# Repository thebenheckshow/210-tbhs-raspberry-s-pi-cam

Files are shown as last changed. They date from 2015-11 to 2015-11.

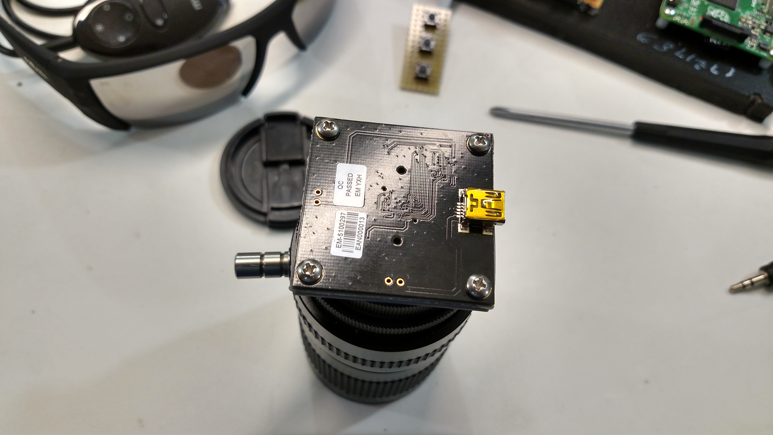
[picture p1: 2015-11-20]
Pictures/IMG_20151013_200145252_HDR.jpg

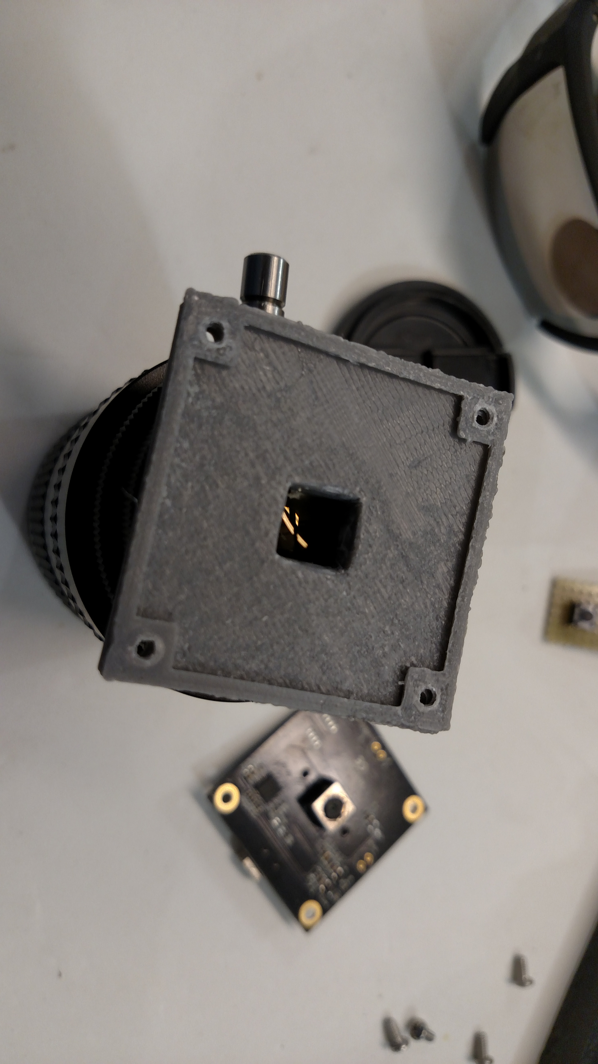
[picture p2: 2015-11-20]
Pictures/IMG_20151013_195946254.jpg

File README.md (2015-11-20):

# 210-tbhs-raspberry-s-pi-cam

The evil Pie Face plans to turn the world to crust, special agent Ben Bondendorf must stop him. In order for Ben to accomplish this he must build some sort of surveillance device that will enable him to stop Pie Face before his evil plan is realized. 

In the first episode Ben and Felix complete the mechanical portion of the build.
http://www.element14.com/community/docs/DOC-79156/l/episode-210-ben-hecks-raspberry-s-pi-cam-part-1-episode

In the second episode Ben and Felix create a control box in the handle of the cooler, write an auto start script for the Pi2, and wire everything together.
http://www.element14.com/community/docs/DOC-79191/l/episode-211-ben-hecks-raspberry-s-pi-cam-part-2-episode

Join the element14 community! - http://www.element14.com/tbhs

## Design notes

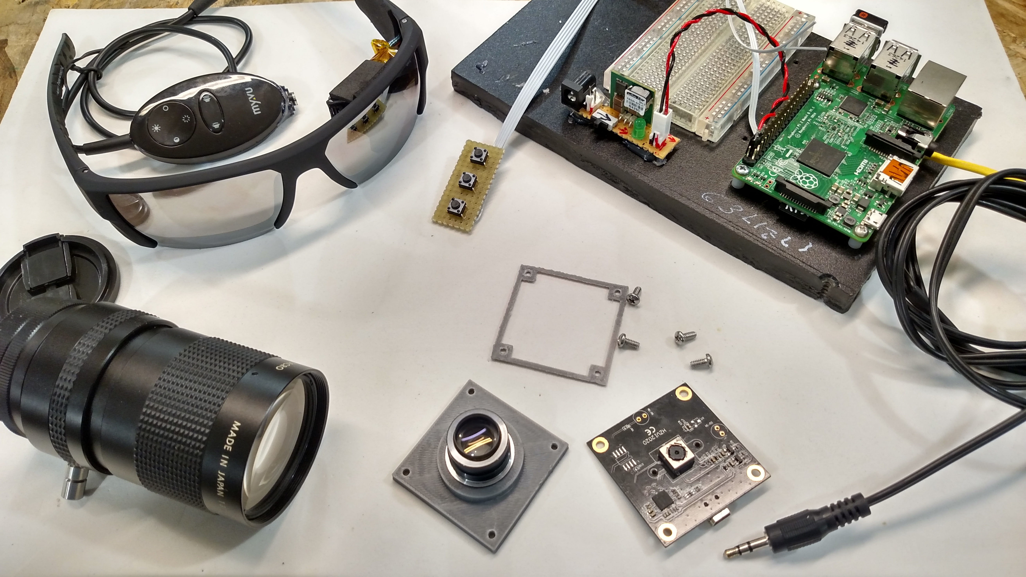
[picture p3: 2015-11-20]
Pictures/IMG_20151013_195322977_HDR.jpg

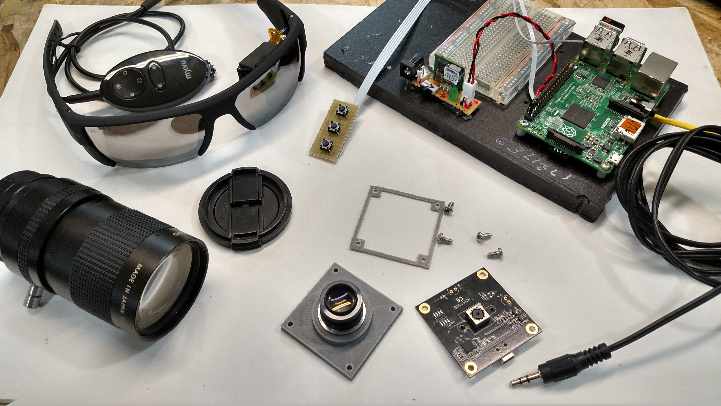
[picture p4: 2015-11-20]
Pictures/IMG_20151013_195359626_HDR.jpg

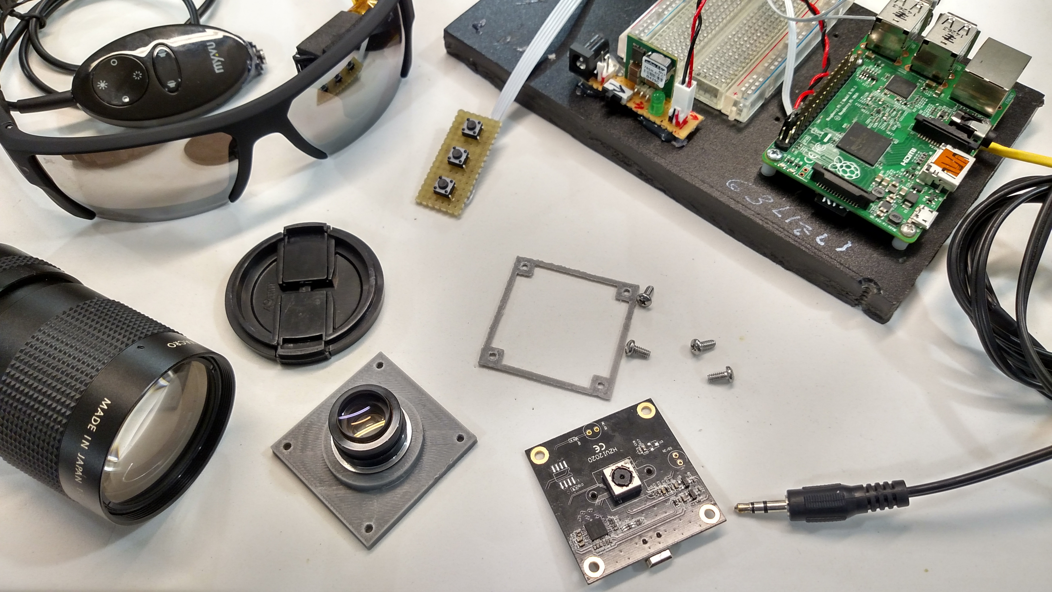
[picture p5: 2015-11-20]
Pictures/IMG_20151013_195439271_HDR.jpg

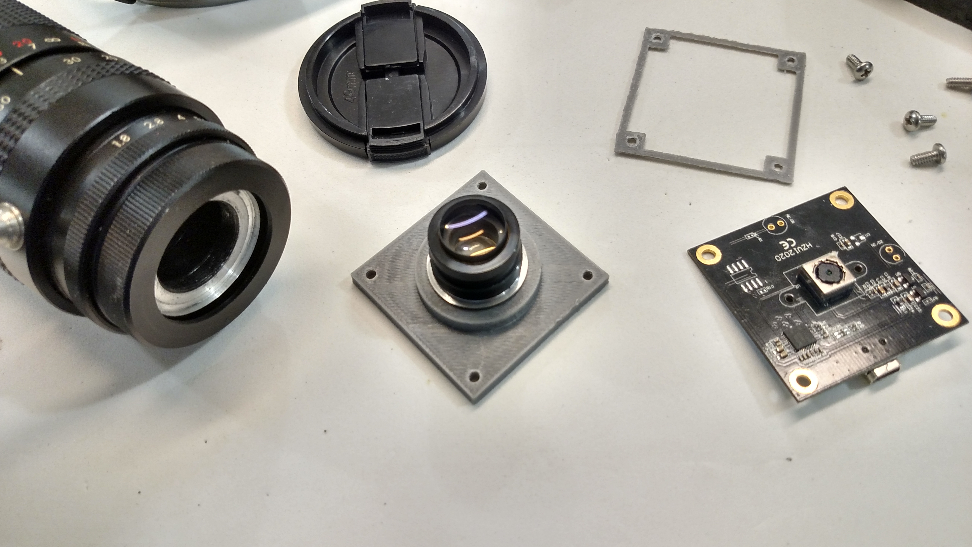
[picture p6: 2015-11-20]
Pictures/IMG_20151013_195614979_HDR.jpg

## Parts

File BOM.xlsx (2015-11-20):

Part | SKU | QTY | Supplier
Raspberry Pi 2 | 38Y6467 | 1 | Newark
PCB Board with isolated solder pads | 01H8753 | 1 | Newark
SWITCH, TACTILE SPST | 19C7994 | 4 | Newark
Through Hole Resistor, Carbon Film, MCF Series, 1 kohm | 38K0327 | 4 | Newark
CAM8200-U MODULE CAMERA MODULE, USB INTERFACE, 5MP | 83X8624 | 1 | Newark
BOARD-BOARD CONNECTOR, SOCKET, 36 POSITION, 1ROW | 18M8296 | 1 | Newark
Linear Regulator DC/DC Converter | 40M6586 | 1 | Newark
Audio cable | 90C0959 | 1 | Newark
Tactile Switch | 19C8258 | 3 | Newark
Kowa TV Zoom Lense 1:1.8/12.5-75 Macro | 1301700 | 1 | Ebay
Wireless dongle | 2638 | 1 | Adafruit
Myvu Personal Media Viewer |  | 1 | Amazon

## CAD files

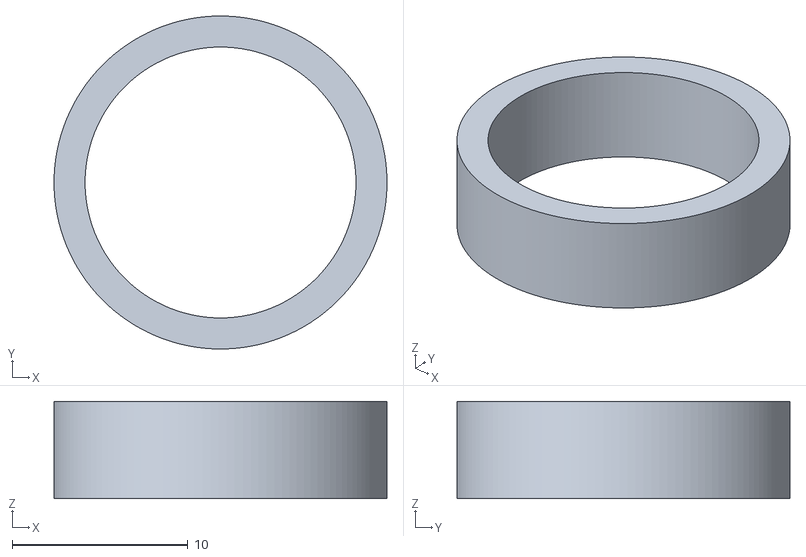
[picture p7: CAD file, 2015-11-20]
Design/Camera_Mount/Outer_Ring_Test.stl
18.9 x 18.9 x 5.54

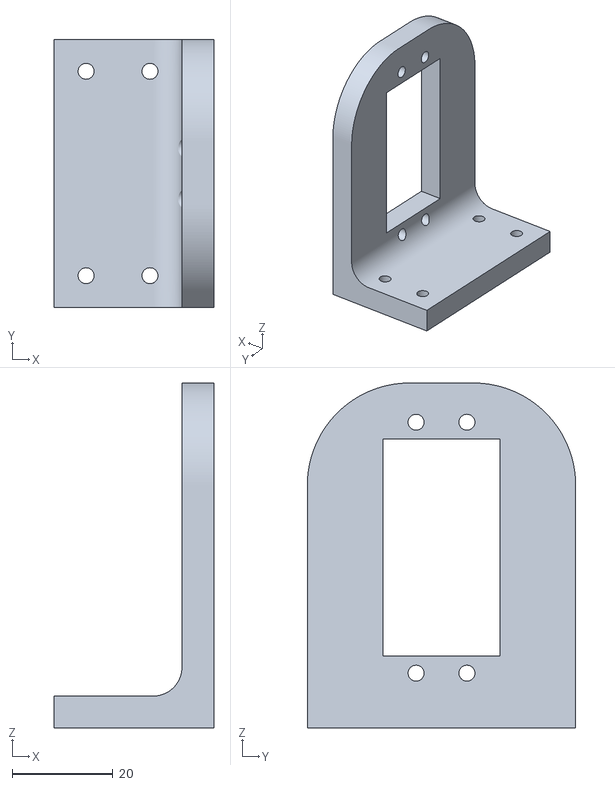
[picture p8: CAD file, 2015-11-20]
Design/STL/Servo Mount.stl
31.8 x 53.3 x 68.6

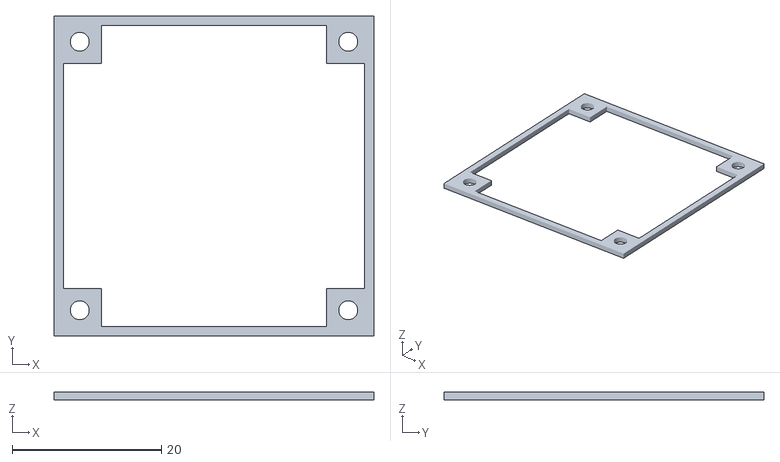
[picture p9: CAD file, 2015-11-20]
Design/STL/spacer.stl
43.0 x 43.0 x 1.02

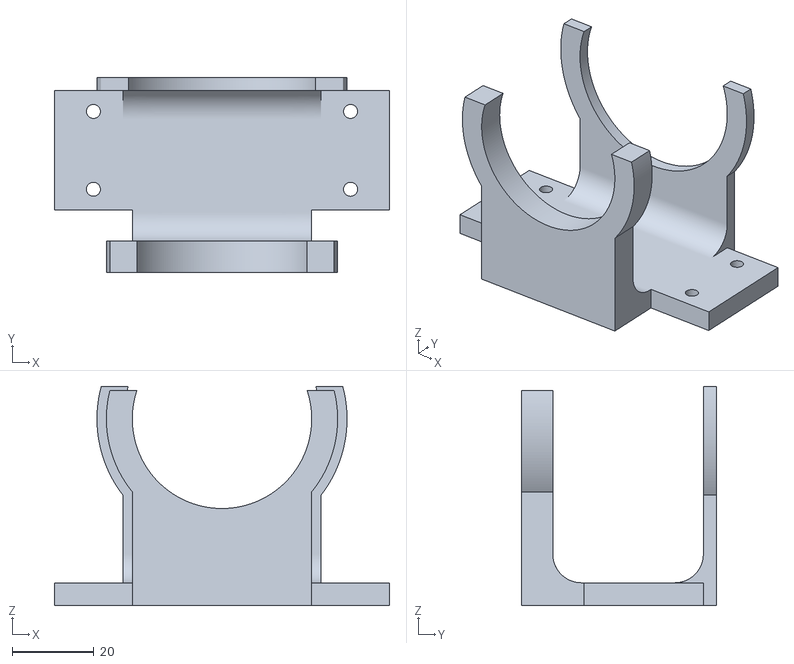
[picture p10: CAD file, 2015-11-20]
Design/STL/rings.stl
82.0 x 47.6 x 53.6

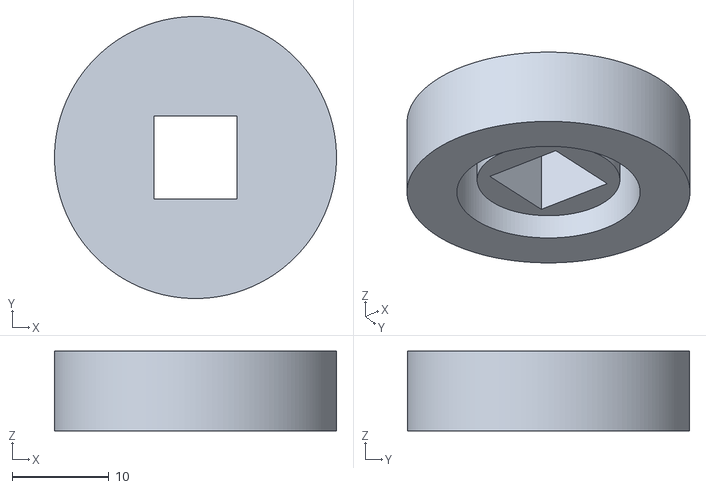
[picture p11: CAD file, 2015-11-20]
Design/STL/camera_mount_test_0.stl
29.2 x 29.2 x 8.26

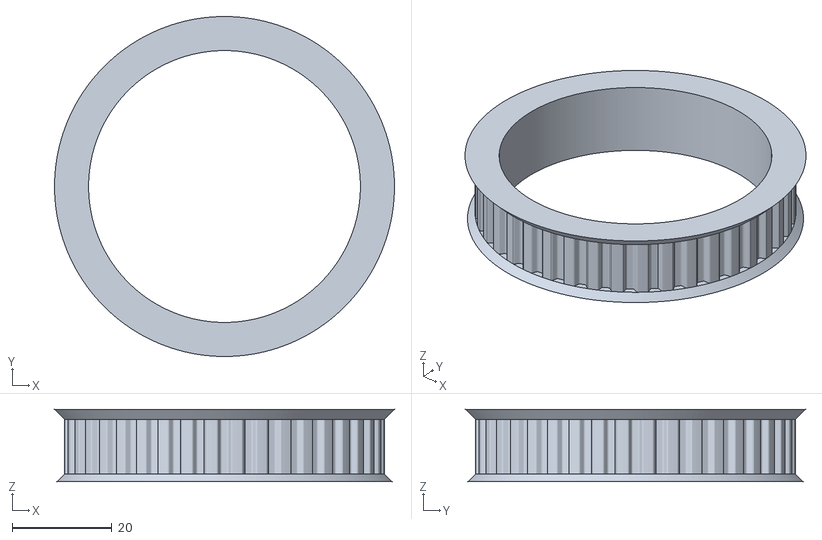
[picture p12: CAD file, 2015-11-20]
Design/STL/zoom pulley.stl
68.2 x 68.2 x 14.5

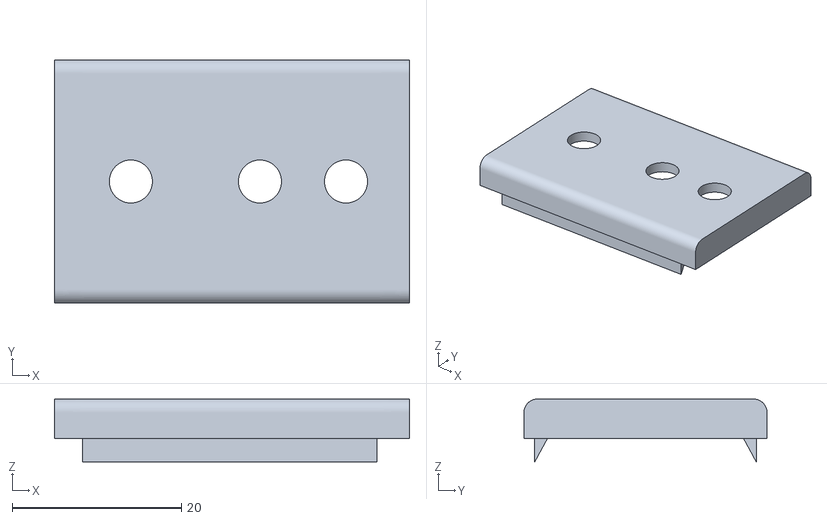
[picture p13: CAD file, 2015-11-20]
Design/STL/top cap.stl
41.9 x 28.7 x 7.43

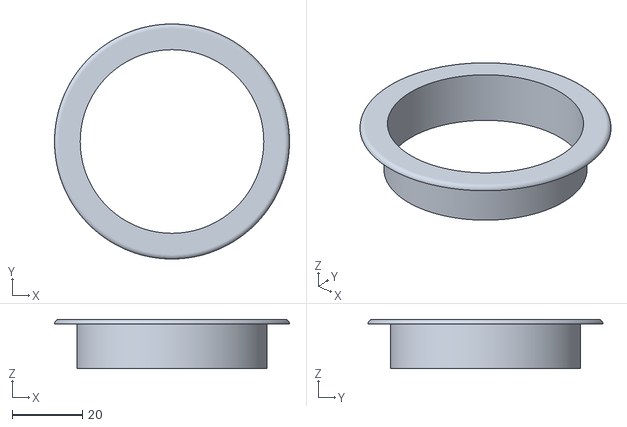
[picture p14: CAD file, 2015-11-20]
Design/STL/Adapter Ring.stl
66.7 x 66.7 x 14.0

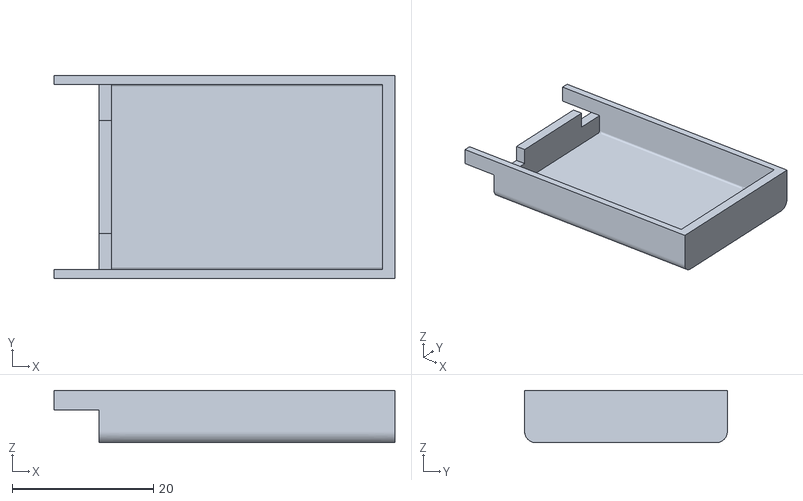
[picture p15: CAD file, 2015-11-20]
Design/STL/bottom cap.stl
48.3 x 28.7 x 7.43

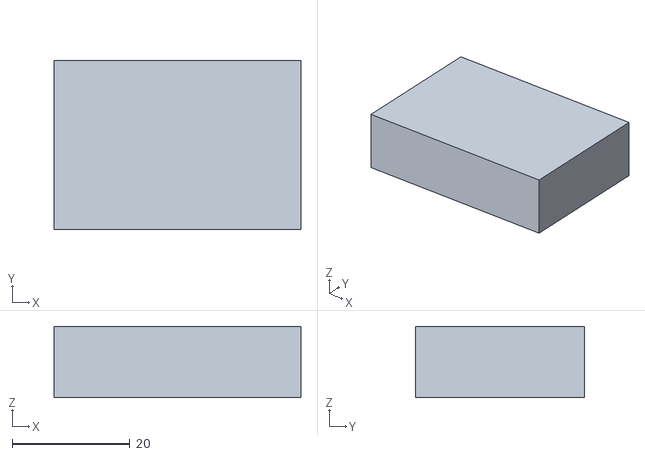
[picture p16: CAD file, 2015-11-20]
Design/STL/handle test 1.stl
41.9 x 28.7 x 12.1

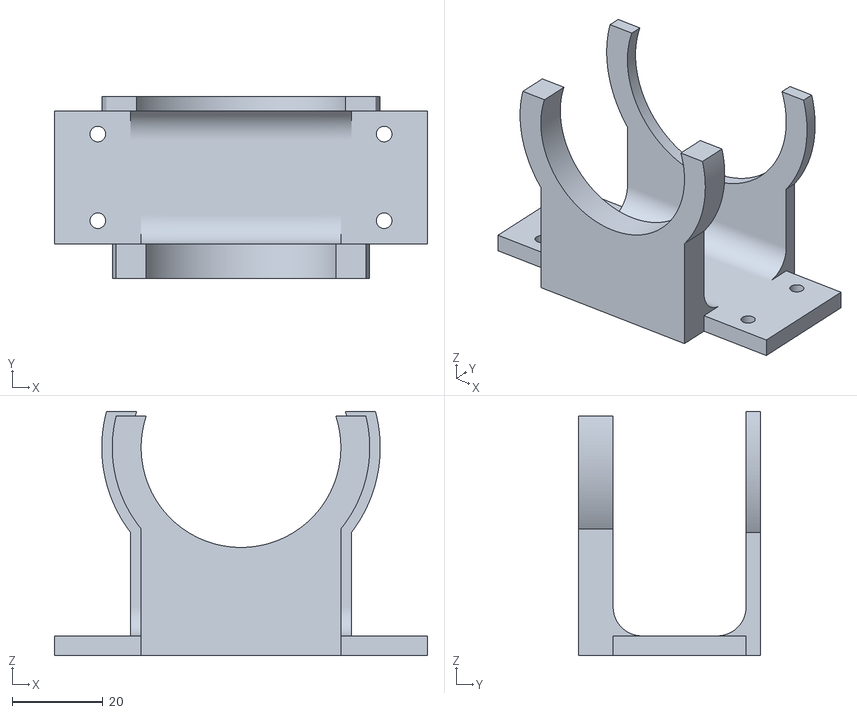
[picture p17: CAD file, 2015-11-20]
Design/STL/ring 2.stl
82.0 x 40.0 x 53.6

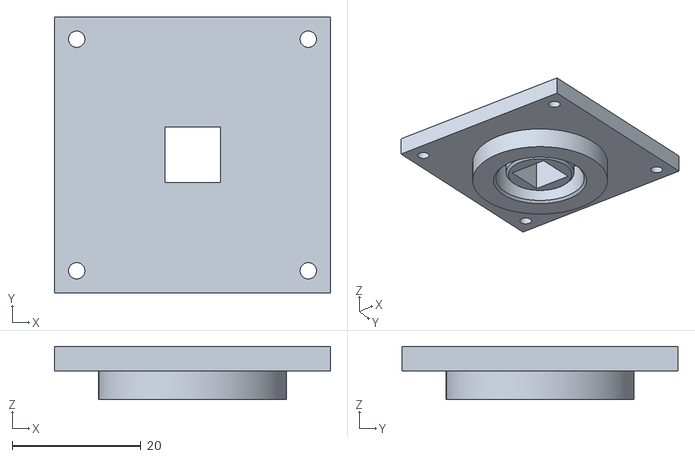
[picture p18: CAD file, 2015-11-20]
Design/STL/camera_mount_test_2.stl
43.0 x 43.0 x 8.26

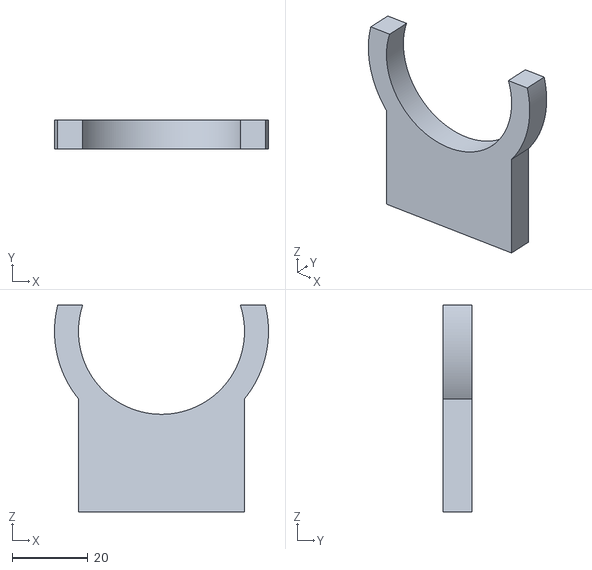
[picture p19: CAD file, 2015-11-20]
Design/STL/ring 1.stl
56.6 x 7.62 x 54.6

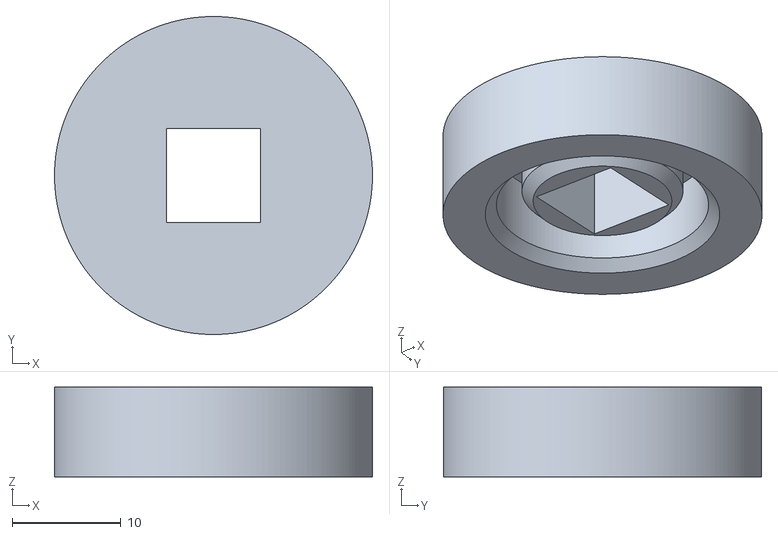
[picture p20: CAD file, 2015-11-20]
Design/STL/camera_mount_test_1.stl
29.2 x 29.2 x 8.26

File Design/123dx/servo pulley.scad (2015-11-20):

// Parametric Pulley with multiple belt profiles
// by droftarts January 2012

// Based on pulleys by:
// http://www.thingiverse.com/thing:11256 by me!
// https://github.com/prusajr/PrusaMendel by Josef Prusa
// http://www.thingiverse.com/thing:3104 by GilesBathgate
// http://www.thingiverse.com/thing:2079 by nophead

// dxf tooth data from http://oem.cadregister.com/asp/PPOW_Entry.asp?company=915217&elementID=07807803/METRIC/URETH/WV0025/F
// pulley diameter checked and modelled from data at http://www.sdp-si.com/D265/HTML/D265T016.html

/**
 * @name Pulley
 * @category Printed
 * @using 1 x m3 nut, normal or nyloc
 * @using 1 x m3x10 set screw or 1 x m3x8 grub screw
 */


// tuneable constants

teeth = 30;			// Number of teeth, standard Mendel T5 belt = 8, gives Outside Diameter of 11.88mm
profile = 3;		// 1=MXL 2=40DP 3=XL 4=H 5=T2.5 6=T5 7=T10 8=AT5 9=HTD_3mm 10=HTD_5mm 11=HTD_8mm 12=GT2_2mm 13=GT2_3mm 14=GT2_5mm

motor_shaft = 7.2;	// NEMA17 motor shaft exact diameter = 5
m3_dia = 3.5;		// 3mm hole diameter
m3_nut_hex = 1;		// 1 for hex, 0 for square nut
m3_nut_flats = 5.9;	// normal M3 hex nut exact width = 5.5
m3_nut_depth = 2.9;	// normal M3 hex nut exact depth = 2.4, nyloc = 4

retainer = 1;		// Belt retainer above teeth, 0 = No, 1 = Yes
retainer_ht = 2;	// height of retainer flange over pulley, standard = 1.5
idler = 1;			// Belt retainer below teeth, 0 = No, 1 = Yes
idler_ht = 1.5;		// height of idler flange over pulley, standard = 1.5

pulley_t_ht = 11;	// length of toothed part of pulley, standard = 12
pulley_b_ht = 0;		// pulley base height, standard = 8. Set to same as idler_ht if you want an idler but no pulley.
pulley_b_dia = 42;	// pulley base diameter, standard = 20
no_of_nuts = 2;		// number of captive nuts required, standard = 1
nut_angle = 180;		// angle between nuts, standard = 90
nut_shaft_distance = 5;	// distance between inner face of nut and shaft, can be negative.


//	********************************
//	** Scaling tooth for good fit **
//	********************************
/*	To improve fit of belt to pulley, set the following constant. Decrease or increase by 0.1mm at a time. We are modelling the *BELT* tooth here, not the tooth on the pulley. Increasing the number will *decrease* the pulley tooth size. Increasing the tooth width will also scale proportionately the tooth depth, to maintain the shape of the tooth, and increase how far into the pulley the tooth is indented. Can be negative */

additional_tooth_width = 0.2; //mm

//	If you need more tooth depth than this provides, adjust the following constant. However, this will cause the shape of the tooth to change.

additional_tooth_depth = 0; //mm

// calculated constants

nut_elevation = pulley_b_ht/2;
m3_nut_points = 2*((m3_nut_flats/2)/cos(30)); // This is needed for the nut trap

// The following set the pulley diameter for a given number of teeth

MXL_pulley_dia = tooth_spacing (2.032,0.254);
40DP_pulley_dia = tooth_spacing (2.07264,0.1778);
XL_pulley_dia = tooth_spacing (5.08,0.254);
H_pulley_dia = tooth_spacing (9.525,0.381);
T2_5_pulley_dia = tooth_spaceing_curvefit (0.7467,0.796,1.026);
T5_pulley_dia = tooth_spaceing_curvefit (0.6523,1.591,1.064);
T10_pulley_dia = tooth_spacing (10,0.93);
AT5_pulley_dia = tooth_spaceing_curvefit (0.6523,1.591,1.064);
HTD_3mm_pulley_dia = tooth_spacing (3,0.381);
HTD_5mm_pulley_dia = tooth_spacing (5,0.5715);
HTD_8mm_pulley_dia = tooth_spacing (8,0.6858);
GT2_2mm_pulley_dia = tooth_spacing (2,0.254);
GT2_3mm_pulley_dia = tooth_spacing (3,0.381);
GT2_5mm_pulley_dia = tooth_spacing (5,0.5715);

// The following calls the pulley creation part, and passes the pulley diameter and tooth width to that module

if ( profile == 1 ) { pulley ( "MXL" , MXL_pulley_dia , 0.508 , 1.321 ); }
if ( profile == 2 ) { pulley ( "40 D.P." , 40DP_pulley_dia , 0.457 , 1.226 ); }
if ( profile == 3 ) { pulley ( "XL" , XL_pulley_dia , 1.27, 3.051 ); }
if ( profile == 4 ) { pulley ( "H" , H_pulley_dia ,1.905 , 5.359 ); }
if ( profile == 5 ) { pulley ( "T2.5" , T2_5_pulley_dia , 0.7 , 1.678 ); }
if ( profile == 6 ) { pulley ( "T5" , T5_pulley_dia , 1.19 , 3.264 ); }
if ( profile == 7 ) { pulley ( "T10" , T10_pulley_dia , 2.5 , 6.13 ); }
if ( profile == 8 ) { pulley ( "AT5" , AT5_pulley_dia , 1.19 , 4.268 ); }
if ( profile == 9 ) { pulley ( "HTD 3mm" , HTD_3mm_pulley_dia , 1.289 , 2.27 ); }
if ( profile == 10 ) { pulley ( "HTD 5mm" , HTD_5mm_pulley_dia , 2.199 , 3.781 ); }
if ( profile == 11 ) { pulley ( "HTD 8mm" , HTD_8mm_pulley_dia , 3.607 , 6.603 ); }
if ( profile == 12 ) { pulley ( "GT2 2mm" , GT2_2mm_pulley_dia , 0.764 , 1.494 ); }
if ( profile == 13 ) { pulley ( "GT2 3mm" , GT2_3mm_pulley_dia , 1.169 , 2.31 ); }
if ( profile == 14 ) { pulley ( "GT2 5mm" , GT2_5mm_pulley_dia , 1.969 , 3.952 ); }

// Functions

function tooth_spaceing_curvefit (b,c,d)
	= ((c * pow(teeth,d)) / (b + pow(teeth,d))) * teeth ;

function tooth_spacing(tooth_pitch,pitch_line_offset)
	= (2*((teeth*tooth_pitch)/(3.14159265*2)-pitch_line_offset)) ;

// Main Module

module pulley( belt_type , pulley_OD , tooth_depth , tooth_width )
	{
	echo (str("Belt type = ",belt_type,"; Number of teeth = ",teeth,"; Pulley Outside Diameter = ",pulley_OD,"mm "));
	tooth_distance_from_centre = sqrt( pow(pulley_OD/2,2) - pow((tooth_width+additional_tooth_width)/2,2));
	tooth_width_scale = (tooth_width + additional_tooth_width ) / tooth_width;
	tooth_depth_scale = ((tooth_depth + additional_tooth_depth ) / tooth_depth) ;


//	************************************************************************
//	*** uncomment the following line if pulley is wider than puller base ***
//	************************************************************************

//	translate ([0,0, pulley_b_ht + pulley_t_ht + retainer_ht ]) rotate ([0,180,0])

	difference()
	 {	 
		union()
		{
			//base
	
			if ( pulley_b_ht < 2 ) { echo ("CAN'T DRAW PULLEY BASE, HEIGHT LESS THAN 2!!!"); } else {
				rotate_extrude($fn=pulley_b_dia*2)
				{
						square([pulley_b_dia/2-1,pulley_b_ht]);
						square([pulley_b_dia/2,pulley_b_ht-1]);
						translate([pulley_b_dia/2-1,pulley_b_ht-1]) circle(1);
				}
			}
	
		difference()
			{
			//shaft - diameter is outside diameter of pulley
			
			translate([0,0,pulley_b_ht]) 
			rotate ([0,0,360/(teeth*4)]) 
			cylinder(r=pulley_OD/2,h=pulley_t_ht, $fn=teeth*4);
	
			//teeth - cut out of shaft
		
			for(i=[1:teeth]) 
			rotate([0,0,i*(360/teeth)])
			translate([0,-tooth_distance_from_centre,pulley_b_ht -1]) 
			scale ([ tooth_width_scale , tooth_depth_scale , 1 ]) 
			{
			if ( profile == 1 ) { MXL();}
			if ( profile == 2 ) { 40DP();}
			if ( profile == 3 ) { XL();}
			if ( profile == 4 ) { H();}
			if ( profile == 5 ) { T2_5();}
			if ( profile == 6 ) { T5();}
			if ( profile == 7 ) { T10();}
			if ( profile == 8 ) { AT5();}
			if ( profile == 9 ) { HTD_3mm();}
			if ( profile == 10 ) { HTD_5mm();}
			if ( profile == 11 ) { HTD_8mm();}
			if ( profile == 12 ) { GT2_2mm();}
			if ( profile == 13 ) { GT2_3mm();}
			if ( profile == 14 ) { GT2_5mm();}
			}

			}
			
		//belt retainer / idler
		if ( retainer > 0 ) {translate ([0,0, pulley_b_ht + pulley_t_ht ]) 
		rotate_extrude($fn=teeth*4)  
		polygon([[0,0],[pulley_OD/2,0],[pulley_OD/2 + retainer_ht , retainer_ht],[0 , retainer_ht],[0,0]]);}
		
		if ( idler > 0 ) {translate ([0,0, pulley_b_ht - idler_ht ]) 
		rotate_extrude($fn=teeth*4)  
		polygon([[0,0],[pulley_OD/2 + idler_ht,0],[pulley_OD/2 , idler_ht],[0 , idler_ht],[0,0]]);}
	
		}
	   
		//hole for motor shaft
		translate([0,0,-1])cylinder(r=motor_shaft/2,h=pulley_b_ht + pulley_t_ht + retainer_ht + 2,$fn=motor_shaft*4);
				
		//captive nut and grub screw holes
	
		if ( pulley_b_ht < m3_nut_flats ) { echo ("CAN'T DRAW CAPTIVE NUTS, HEIGHT LESS THAN NUT DIAMETER!!!"); } else {
		if ( (pulley_b_dia - motor_shaft)/2 < m3_nut_depth + 3 ) { echo ("CAN'T DRAW CAPTIVE NUTS, DIAMETER TOO SMALL FOR NUT DEPTH!!!"); } else {
	
			for(j=[1:no_of_nuts]) rotate([0,0,j*nut_angle])
			translate([0,0,nut_elevation])rotate([90,0,0])
	
			union()
			{
				//entrance
				translate([0,-pulley_b_ht/4-0.5,motor_shaft/2+m3_nut_depth/2+nut_shaft_distance]) cube([m3_nut_flats,pulley_b_ht/2+1,m3_nut_depth],center=true);
	
				//nut
				if ( m3_nut_hex > 0 )
					{
						// hex nut
						translate([0,0.25,motor_shaft/2+m3_nut_depth/2+nut_shaft_distance]) rotate([0,0,30]) cylinder(r=m3_nut_points/2,h=m3_nut_depth,center=true,$fn=6);
					} else {
						// square nut
						translate([0,0.25,motor_shaft/2+m3_nut_depth/2+nut_shaft_distance]) cube([m3_nut_flats,m3_nut_flats,m3_nut_depth],center=true);
					}
	
				//grub screw hole
				rotate([0,0,22.5])cylinder(r=m3_dia/2,h=pulley_b_dia/2+1,$fn=8);
			}
		}}
	 }
	   
	}


// Tooth profile modules
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

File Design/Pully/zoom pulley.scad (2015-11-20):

// Parametric Pulley with multiple belt profiles
// by droftarts January 2012

// Based on pulleys by:
// http://www.thingiverse.com/thing:11256 by me!
// https://github.com/prusajr/PrusaMendel by Josef Prusa
// http://www.thingiverse.com/thing:3104 by GilesBathgate
// http://www.thingiverse.com/thing:2079 by nophead

// dxf tooth data from http://oem.cadregister.com/asp/PPOW_Entry.asp?company=915217&elementID=07807803/METRIC/URETH/WV0025/F
// pulley diameter checked and modelled from data at http://www.sdp-si.com/D265/HTML/D265T016.html

/**
 * @name Pulley
 * @category Printed
 * @using 1 x m3 nut, normal or nyloc
 * @using 1 x m3x10 set screw or 1 x m3x8 grub screw
 */


// tuneable constants

teeth = 40;			// Number of teeth, standard Mendel T5 belt = 8, gives Outside Diameter of 11.88mm
profile = 3;		// 1=MXL 2=40DP 3=XL 4=H 5=T2.5 6=T5 7=T10 8=AT5 9=HTD_3mm 10=HTD_5mm 11=HTD_8mm 12=GT2_2mm 13=GT2_3mm 14=GT2_5mm

motor_shaft = 54.5;	// NEMA17 motor shaft exact diameter = 5
m3_dia = 3.5;		// 3mm hole diameter
m3_nut_hex = 1;		// 1 for hex, 0 for square nut
m3_nut_flats = 5.9;	// normal M3 hex nut exact width = 5.5
m3_nut_depth = 2.9;	// normal M3 hex nut exact depth = 2.4, nyloc = 4

retainer = 1;		// Belt retainer above teeth, 0 = No, 1 = Yes
retainer_ht = 2;	// height of retainer flange over pulley, standard = 1.5
idler = 1;			// Belt retainer below teeth, 0 = No, 1 = Yes
idler_ht = 1.5;		// height of idler flange over pulley, standard = 1.5

pulley_t_ht = 11;	// length of toothed part of pulley, standard = 12
pulley_b_ht = 11;		// pulley base height, standard = 8. Set to same as idler_ht if you want an idler but no pulley.
pulley_b_dia = 42;	// pulley base diameter, standard = 20
no_of_nuts = 2;		// number of captive nuts required, standard = 1
nut_angle = 180;		// angle between nuts, standard = 90
nut_shaft_distance = 5;	// distance between inner face of nut and shaft, can be negative.


//	********************************
//	** Scaling tooth for good fit **
//	********************************
/*	To improve fit of belt to pulley, set the following constant. Decrease or increase by 0.1mm at a time. We are modelling the *BELT* tooth here, not the tooth on the pulley. Increasing the number will *decrease* the pulley tooth size. Increasing the tooth width will also scale proportionately the tooth depth, to maintain the shape of the tooth, and increase how far into the pulley the tooth is indented. Can be negative */

additional_tooth_width = 0.2; //mm

//	If you need more tooth depth than this provides, adjust the following constant. However, this will cause the shape of the tooth to change.

additional_tooth_depth = 0; //mm

// calculated constants

nut_elevation = pulley_b_ht/2;
m3_nut_points = 2*((m3_nut_flats/2)/cos(30)); // This is needed for the nut trap

// The following set the pulley diameter for a given number of teeth

MXL_pulley_dia = tooth_spacing (2.032,0.254);
40DP_pulley_dia = tooth_spacing (2.07264,0.1778);
XL_pulley_dia = tooth_spacing (5.08,0.254);
H_pulley_dia = tooth_spacing (9.525,0.381);
T2_5_pulley_dia = tooth_spaceing_curvefit (0.7467,0.796,1.026);
T5_pulley_dia = tooth_spaceing_curvefit (0.6523,1.591,1.064);
T10_pulley_dia = tooth_spacing (10,0.93);
AT5_pulley_dia = tooth_spaceing_curvefit (0.6523,1.591,1.064);
HTD_3mm_pulley_dia = tooth_spacing (3,0.381);
HTD_5mm_pulley_dia = tooth_spacing (5,0.5715);
HTD_8mm_pulley_dia = tooth_spacing (8,0.6858);
GT2_2mm_pulley_dia = tooth_spacing (2,0.254);
GT2_3mm_pulley_dia = tooth_spacing (3,0.381);
GT2_5mm_pulley_dia = tooth_spacing (5,0.5715);

// The following calls the pulley creation part, and passes the pulley diameter and tooth width to that module

if ( profile == 1 ) { pulley ( "MXL" , MXL_pulley_dia , 0.508 , 1.321 ); }
if ( profile == 2 ) { pulley ( "40 D.P." , 40DP_pulley_dia , 0.457 , 1.226 ); }
if ( profile == 3 ) { pulley ( "XL" , XL_pulley_dia , 1.27, 3.051 ); }
if ( profile == 4 ) { pulley ( "H" , H_pulley_dia ,1.905 , 5.359 ); }
if ( profile == 5 ) { pulley ( "T2.5" , T2_5_pulley_dia , 0.7 , 1.678 ); }
if ( profile == 6 ) { pulley ( "T5" , T5_pulley_dia , 1.19 , 3.264 ); }
if ( profile == 7 ) { pulley ( "T10" , T10_pulley_dia , 2.5 , 6.13 ); }
if ( profile == 8 ) { pulley ( "AT5" , AT5_pulley_dia , 1.19 , 4.268 ); }
if ( profile == 9 ) { pulley ( "HTD 3mm" , HTD_3mm_pulley_dia , 1.289 , 2.27 ); }
if ( profile == 10 ) { pulley ( "HTD 5mm" , HTD_5mm_pulley_dia , 2.199 , 3.781 ); }
if ( profile == 11 ) { pulley ( "HTD 8mm" , HTD_8mm_pulley_dia , 3.607 , 6.603 ); }
if ( profile == 12 ) { pulley ( "GT2 2mm" , GT2_2mm_pulley_dia , 0.764 , 1.494 ); }
if ( profile == 13 ) { pulley ( "GT2 3mm" , GT2_3mm_pulley_dia , 1.169 , 2.31 ); }
if ( profile == 14 ) { pulley ( "GT2 5mm" , GT2_5mm_pulley_dia , 1.969 , 3.952 ); }

// Functions

function tooth_spaceing_curvefit (b,c,d)
	= ((c * pow(teeth,d)) / (b + pow(teeth,d))) * teeth ;

function tooth_spacing(tooth_pitch,pitch_line_offset)
	= (2*((teeth*tooth_pitch)/(3.14159265*2)-pitch_line_offset)) ;

// Main Module

module pulley( belt_type , pulley_OD , tooth_depth , tooth_width )
	{
	echo (str("Belt type = ",belt_type,"; Number of teeth = ",teeth,"; Pulley Outside Diameter = ",pulley_OD,"mm "));
	tooth_distance_from_centre = sqrt( pow(pulley_OD/2,2) - pow((tooth_width+additional_tooth_width)/2,2));
	tooth_width_scale = (tooth_width + additional_tooth_width ) / tooth_width;
	tooth_depth_scale = ((tooth_depth + additional_tooth_depth ) / tooth_depth) ;


//	************************************************************************
//	*** uncomment the following line if pulley is wider than puller base ***
//	************************************************************************

//	translate ([0,0, pulley_b_ht + pulley_t_ht + retainer_ht ]) rotate ([0,180,0])

	difference()
	 {	 
		union()
		{
			//base
	
			if ( pulley_b_ht < 2 ) { echo ("CAN'T DRAW PULLEY BASE, HEIGHT LESS THAN 2!!!"); } else {
				rotate_extrude($fn=pulley_b_dia*2)
				{
						square([pulley_b_dia/2-1,pulley_b_ht]);
						square([pulley_b_dia/2,pulley_b_ht-1]);
						translate([pulley_b_dia/2-1,pulley_b_ht-1]) circle(1);
				}
			}
	
		difference()
			{
			//shaft - diameter is outside diameter of pulley
			
			translate([0,0,pulley_b_ht]) 
			rotate ([0,0,360/(teeth*4)]) 
			cylinder(r=pulley_OD/2,h=pulley_t_ht, $fn=teeth*4);
	
			//teeth - cut out of shaft
		
			for(i=[1:teeth]) 
			rotate([0,0,i*(360/teeth)])
			translate([0,-tooth_distance_from_centre,pulley_b_ht -1]) 
			scale ([ tooth_width_scale , tooth_depth_scale , 1 ]) 
			{
			if ( profile == 1 ) { MXL();}
			if ( profile == 2 ) { 40DP();}
			if ( profile == 3 ) { XL();}
			if ( profile == 4 ) { H();}
			if ( profile == 5 ) { T2_5();}
			if ( profile == 6 ) { T5();}
			if ( profile == 7 ) { T10();}
			if ( profile == 8 ) { AT5();}
			if ( profile == 9 ) { HTD_3mm();}
			if ( profile == 10 ) { HTD_5mm();}
			if ( profile == 11 ) { HTD_8mm();}
			if ( profile == 12 ) { GT2_2mm();}
			if ( profile == 13 ) { GT2_3mm();}
			if ( profile == 14 ) { GT2_5mm();}
			}

			}
			
		//belt retainer / idler
		if ( retainer > 0 ) {translate ([0,0, pulley_b_ht + pulley_t_ht ]) 
		rotate_extrude($fn=teeth*4)  
		polygon([[0,0],[pulley_OD/2,0],[pulley_OD/2 + retainer_ht , retainer_ht],[0 , retainer_ht],[0,0]]);}
		
		if ( idler > 0 ) {translate ([0,0, pulley_b_ht - idler_ht ]) 
		rotate_extrude($fn=teeth*4)  
		polygon([[0,0],[pulley_OD/2 + idler_ht,0],[pulley_OD/2 , idler_ht],[0 , idler_ht],[0,0]]);}
	
		}
	   
		//hole for motor shaft
		translate([0,0,-1])cylinder(r=motor_shaft/2,h=pulley_b_ht + pulley_t_ht + retainer_ht + 2,$fn=motor_shaft*4);
				
		//captive nut and grub screw holes
	
		if ( pulley_b_ht < m3_nut_flats ) { echo ("CAN'T DRAW CAPTIVE NUTS, HEIGHT LESS THAN NUT DIAMETER!!!"); } else {
		if ( (pulley_b_dia - motor_shaft)/2 < m3_nut_depth + 3 ) { echo ("CAN'T DRAW CAPTIVE NUTS, DIAMETER TOO SMALL FOR NUT DEPTH!!!"); } else {
	
			for(j=[1:no_of_nuts]) rotate([0,0,j*nut_angle])
			translate([0,0,nut_elevation])rotate([90,0,0])
	
			union()
			{
				//entrance
				translate([0,-pulley_b_ht/4-0.5,motor_shaft/2+m3_nut_depth/2+nut_shaft_distance]) cube([m3_nut_flats,pulley_b_ht/2+1,m3_nut_depth],center=true);
	
				//nut
				if ( m3_nut_hex > 0 )
					{
						// hex nut
						translate([0,0.25,motor_shaft/2+m3_nut_depth/2+nut_shaft_distance]) rotate([0,0,30]) cylinder(r=m3_nut_points/2,h=m3_nut_depth,center=true,$fn=6);
					} else {
						// square nut
						translate([0,0.25,motor_shaft/2+m3_nut_depth/2+nut_shaft_distance]) cube([m3_nut_flats,m3_nut_flats,m3_nut_depth],center=true);
					}
	
				//grub screw hole
				rotate([0,0,22.5])cylinder(r=m3_dia/2,h=pulley_b_dia/2+1,$fn=8);
			}
		}}
	 }
	   
	}


// Tooth profile modules
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

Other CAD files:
Design/STL/ring 3.stl
Design/STL/servo pulley.stl

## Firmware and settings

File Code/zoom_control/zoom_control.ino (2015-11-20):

#include <Servo.h> 
 
Servo myservo;

int pos = 90;
float velocity = 1;

#define out   9
#define in  10

#define outLimit 150
#define inLimit  5


void setup() 
{ 
  
  Serial.begin(115200);
  
  myservo.attach(3);  // attaches the servo on pin 9 to the servo object 

  pinMode(in, INPUT);
  digitalWrite(in, 1);
  
  pinMode(out, INPUT);
  digitalWrite(out, 1);

} 
 
void loop() 
{ 
                               
  myservo.write(pos);              // tell servo to go to position in variable 'pos' 

  if (digitalRead(in) == 0 and pos > inLimit) {
    
    pos -= velocity;
    
    velocity += .1;

  }

  if (digitalRead(out) == 0 and pos < outLimit) {
    
    pos += velocity;

    velocity += .1;

  }
  
  if (digitalRead(in) and digitalRead(out)) {
  
    velocity = 1;
    
  }
  
  delay(25);
  
  Serial.print(pos);
  Serial.println(" ");

} 
